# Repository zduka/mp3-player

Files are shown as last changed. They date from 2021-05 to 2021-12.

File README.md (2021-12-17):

# MP3 Player

A simple and pretty low quality mp3 player, fm radio and a walkie-talkie with some extra features. With stereo headphones (where supported) and a single even lower quality speaker in the box. MP3 files are stored on an SD card, powered by a single Li-Ion 18650 cell, with USB-C port for charging (power only). 

The player can be controlled via two push-button knobs and more advanced settings can be specified via either the player's webpage.

For a "user manual" see the documentation, this readme is for technical information only. 

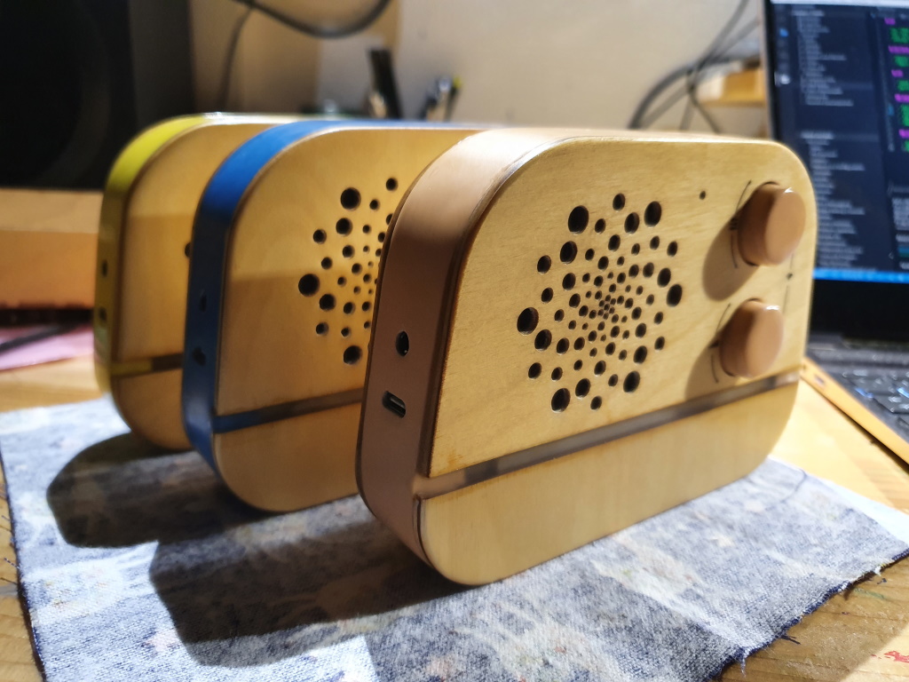
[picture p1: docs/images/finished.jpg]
Finished player


# Software

The player uses 2 MCUs - ATTiny and ESP8266. ESP acts as the main controller, while ATTiny takes care of power management and peripherals. Communication between the chips is done via I2C bus. ATTiny and the LED strip runs directly off the battery voltage, while a SMPS to 3v3 provides power for the audio output and the ESP8266. 

In sleep mode, only the ATTiny and input buttons circuitry is powered and ATTiny is in sleep mode, waking up each second for timekeeping. 

> When flashing the ESP chip, make sure power won't be terminated by ATTiny in the middle of the transaction by shorting the 3V3 jumper wire on the pcb. To perform a full reflash of both chips, start with ESP8266, when done don't reset it and flash AtTiny immediately. When AtTiny is done, it will reset (power on) the ESP as well. 

# Hardware & Assembly Guide

## Assembly Guide

> This is also heavily dependent on how tight you are with the parts and how great your soldering skills are. I was tight with parts and my soldering skills are very limited:)

### Enclosure

Glue together the upper part and the bottom corners. Make sure to insert the screw nuts in the appropriate places and glue them. Glue the bottom, left and right plates. Sand and paint the finished middle frame. 

Glue the bottom part of the front plate. Then glue in the translucent plastic strip with epoxy and the top front plate.

### USB-C Li-Ion charger

Desolder both LEDs and then put a 10k resistor (1206 is fine) instead of the charging LED (red, closer to the USB connector). Connect the charging pin to the connector closer to the connector. Desolder R3 and replace it with 2k7 resistor (through hole) directly from GND to terminal 2 of TP4056 to lower the charging current. Desolder the LEDs and replace the one closer to the USB-C connector with a 10k resistor (this will be a pull-up for the charging sense). 

Attach wires (+5V USB, +, -, charging and long connectors to the battery). When fitted in the enclosure, solder the ends to the battery holder. The battery holder is reversed so that it does not have to be glued and the wires won't obstruct the translucent LED strip below. 

### LED Strip

The LED strip consists of 8 neopixel-style LEDs soldered together. Then glue the strip in place. Make sure the glue does not obstruct the screw mountholes. 

### Main PCB

Take the 3v3 SMPS a saw off the mounthole bit and lower part of connector holes to make it castellated. Then solder the regulator, all the ICs (w/o radio and ESP8266), the MOSFETs (2x), diode and inductors. Solder the 3v3 enable header and debug header. Power on via the power connector, check first that ATTiny has power and that power levels are good and power consuption is small. Then short the 3v3 header to enable 3v3 via SMPS and check the voltage and current draw. 

Solder the capacitor for neopixels strip isolation, attach neopixels, and flash ATTiny with the neopixel test (`-DTEST_NEOPIXEL`). The pixels should flash.

Solder the remaining audio path (resistors and caps) and the radio module. Then solder the 3v3 isolation capacitors. Power on and flash ATTiny with `-DTEST_RADIO`. Attach a speaker or headphones and run. Radio should start playing (you might need to change the station frequency if you want to hear stuff). 

Solder everything else on the main board, but not the control knobs. Flash ATTiny and ESP8266 with the normal code, add empty SD card and power on. A welcome MP3 should play. 

Put the knobs in (don't solder yet), and put the whole PCB in the enclosure, attach with screws. Use hard paper strips to center the knobs in the front panel holes properly and when secured, solder the knobs. Check that everything works mechanically.

Solder the microphone board. First the IC, then all SMT parts and finally the microphone. Solder long headers, put these through the holes in pain pcb  board and when the distance is proper, solder them to the main PCB Board as well. 

Solder the antenna wire. 

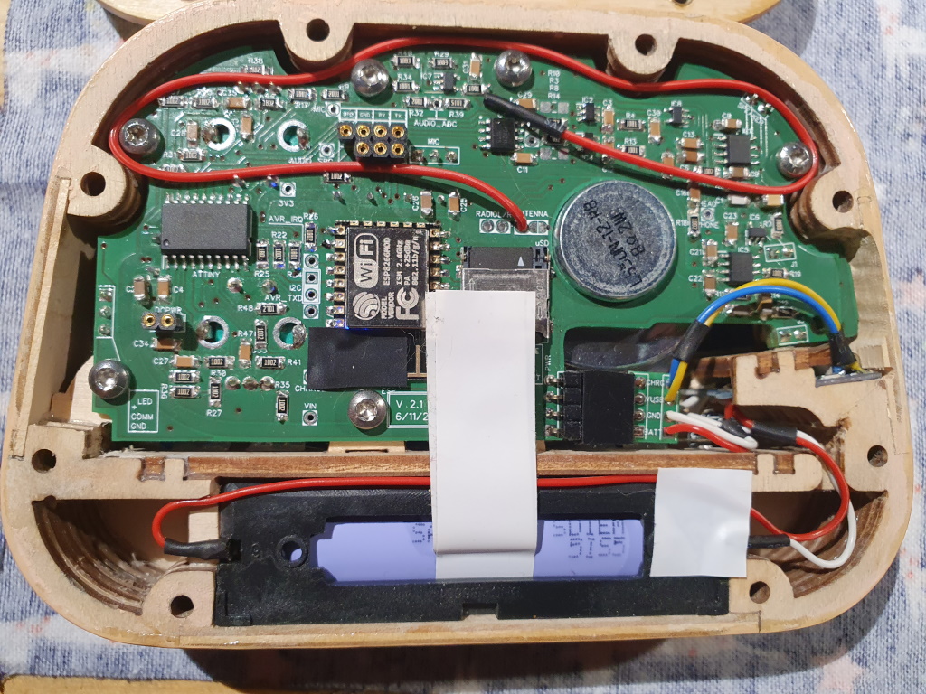
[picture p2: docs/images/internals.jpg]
Internals


### Final Assembly

Attach the speaker and slide the PCB with knobs on in the enclosure, attching the neopixels while doing so. Fix with all screws. Secure the power connector. Cover the blue ESP8266 diode. Attach the backplate.

## Main PCB Description

## ESP8266 Core

### Exceptions Decoder

- tools line in `~/snap/arduino/current/Arduino/tools`

https://github.com/me-no-dev/EspExceptionDecoder

Use old bootstrap because it is smaller

https://getbootstrap.com/docs/3.4/customize/

Bootstrap code must be updated to look for fonts in "." and then change the filenames so that they are short enouygh for littlefs (glyphicons.woff2)

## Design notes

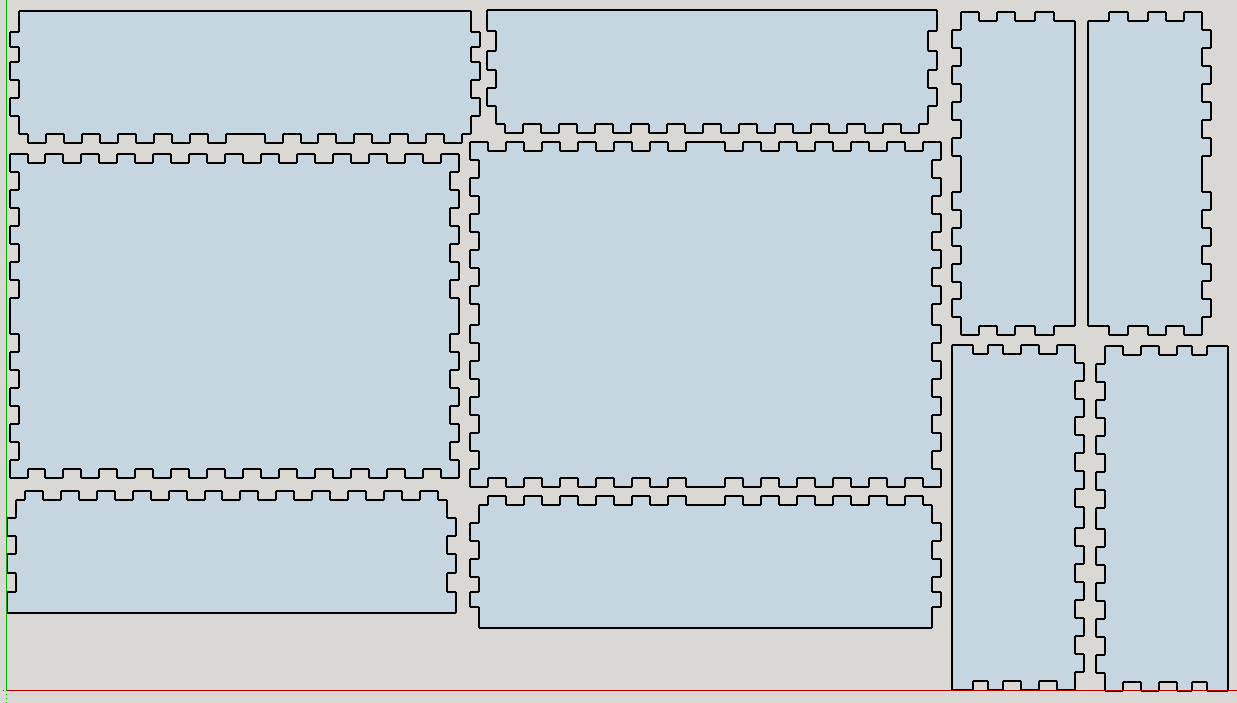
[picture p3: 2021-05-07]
hardware/box-preview.png

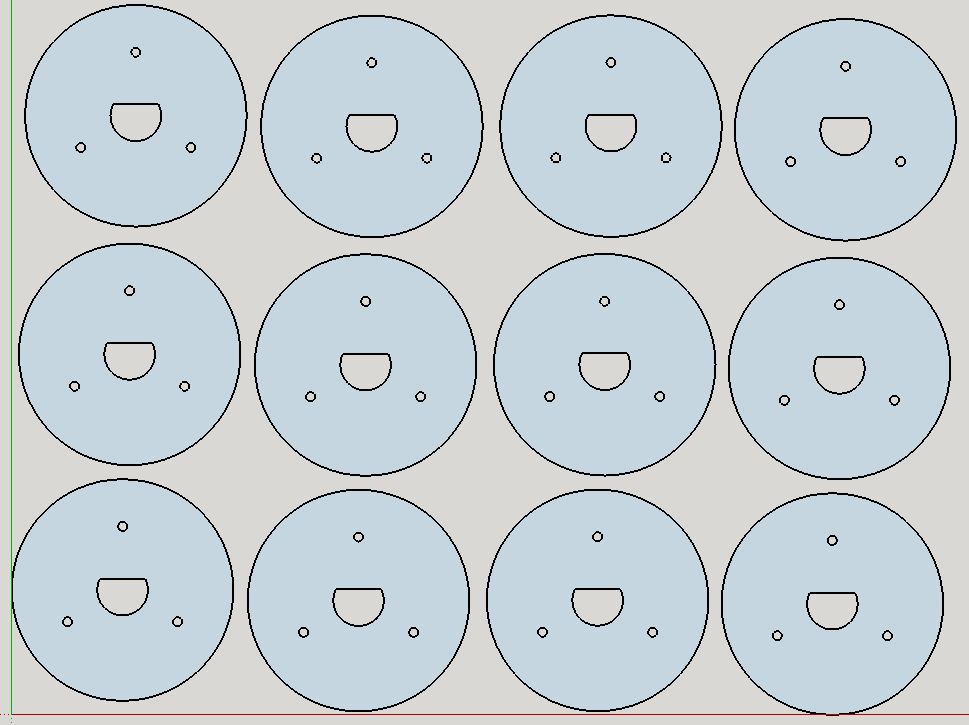
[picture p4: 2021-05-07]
hardware/plexiglass-2mm-preview.png

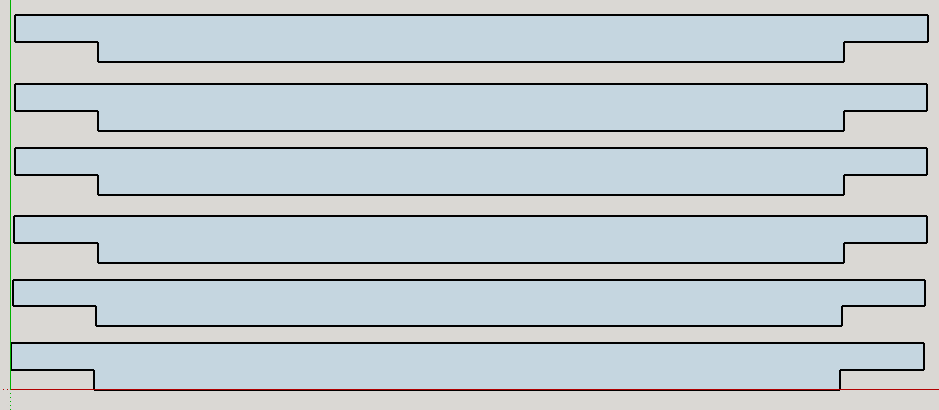
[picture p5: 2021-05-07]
hardware/plexiglass-4mm-preview.png

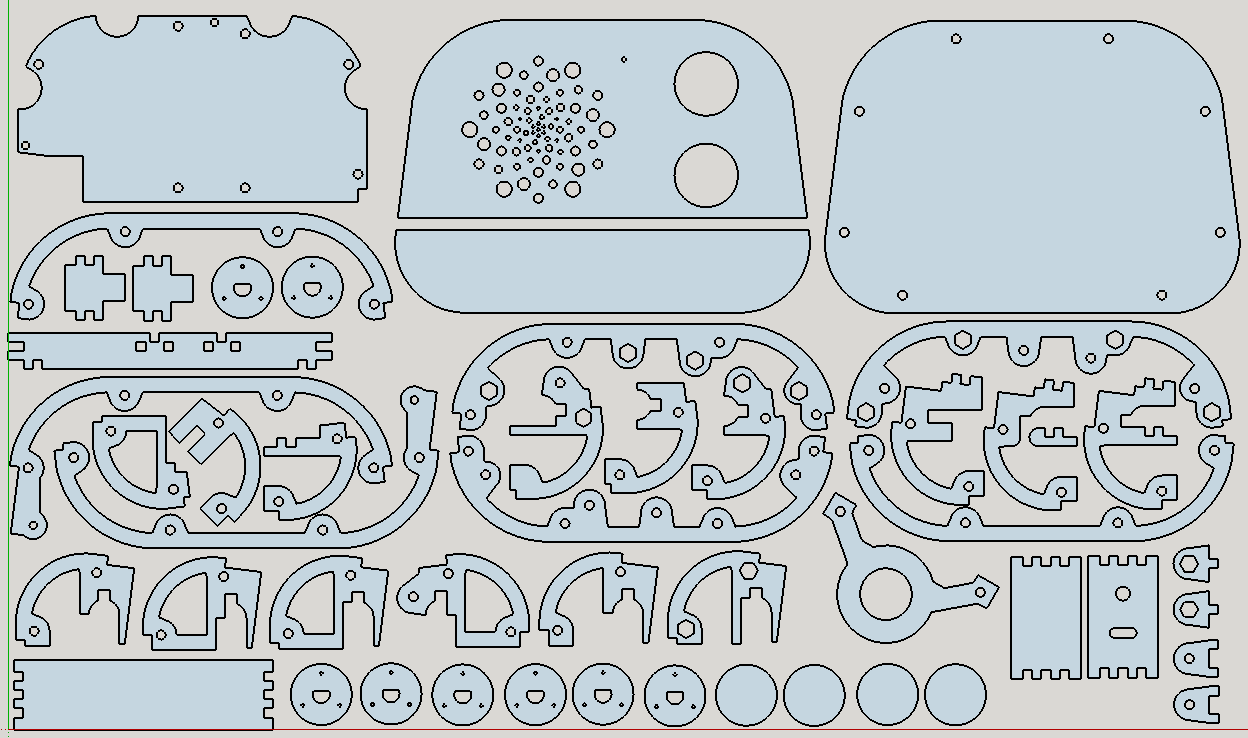
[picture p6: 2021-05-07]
hardware/player-preview.png

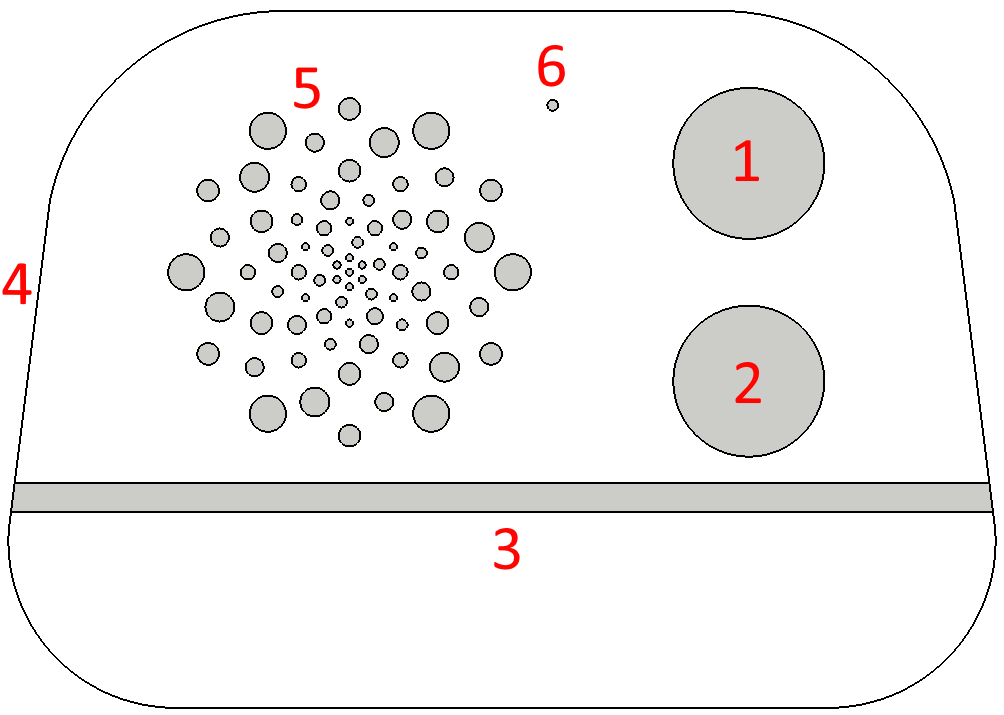
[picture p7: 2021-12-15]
docs/player.png

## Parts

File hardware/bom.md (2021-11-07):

# ICs & Semiconductors

ATTiny3216              1   13
ESP12-F                 1   2
BAT60J                  2   6       ???
TPA311                  2   7
TS5A63157               2   10
MCP6001/MCP6401         3   6/0     15/15
74LVC1G04W5-7           1   10 
DMP1045U                2   15
PT8211                  1   2/3?

# Modules & Extras

Rotary Encoder          2   5       2?      https://cz.mouser.com/ProductDetail/652-PEC12R-4220F-S24       
Microphone              1   2
Radio(RDA5807)          1   2/3?
uSD Holder              1   2
Adafruit 3V3 Buck-Boost 1   2       3    
Inductor 470uH          2   4
Speaker                 1   2               https://www.gme.cz/reproduktor-ls50n-12-r8-50mm-8ohm-2w
Headphones Conn         1   2       1       https://cz.mouser.com/ProductDetail/490-SJ-43514-SMT-TR
USB-C Li-Ion Charger    1   2
18650 Battery Holder    1   2
18650 Li-Ion Battery    1   

# Capacitors

5p                      2           10
15p                     1           10
10n                     2   /8      10
100n                    18  /66     20
0.47u                   2           10
1u                      2   /18+9   -
2u2                     2   /1      10
4u7                     1           10
10u                     3   /9      10
220u                    2   /1      4

1000u                   3

# Resistors

180R                    2   /18     -
1k                      5   /35     -
1k8                     2   /15     -
2k                      2           20
2k7                     1           10
5k1                     1           10
5k6                     1           10
10k                     24  /52     100
51k                     2           10
75k                     1           10
100k                    5   /54     -

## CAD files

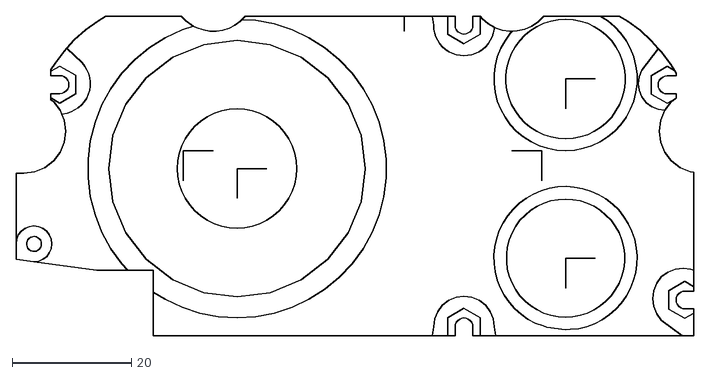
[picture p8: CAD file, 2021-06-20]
hardware/board-large.dxf
113.5 x 53.5

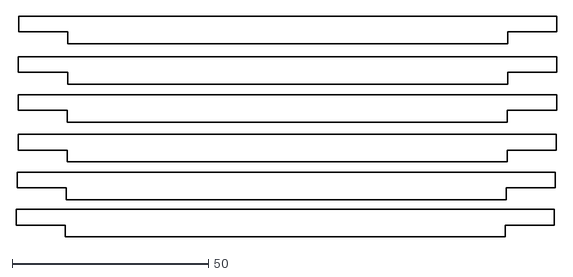
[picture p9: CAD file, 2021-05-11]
hardware/plexiglass-4mm.dxf
137.6 x 56.2

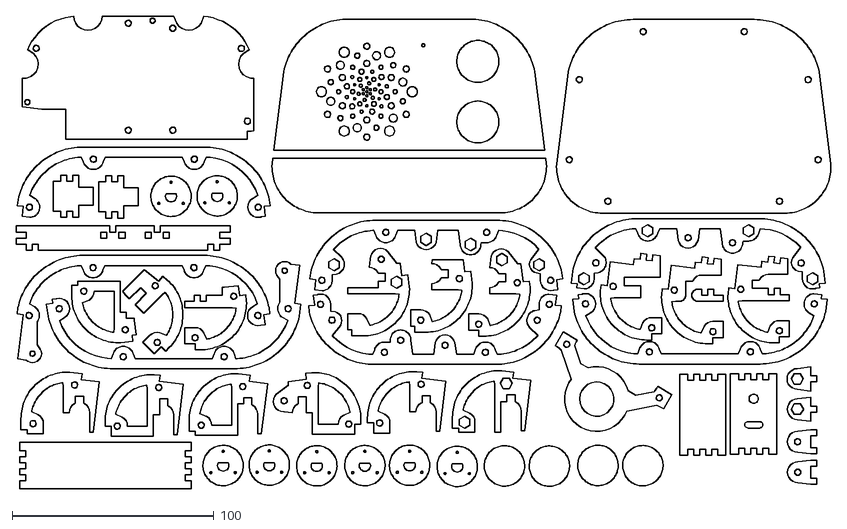
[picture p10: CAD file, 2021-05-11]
hardware/player.dxf
403.7 x 234.2

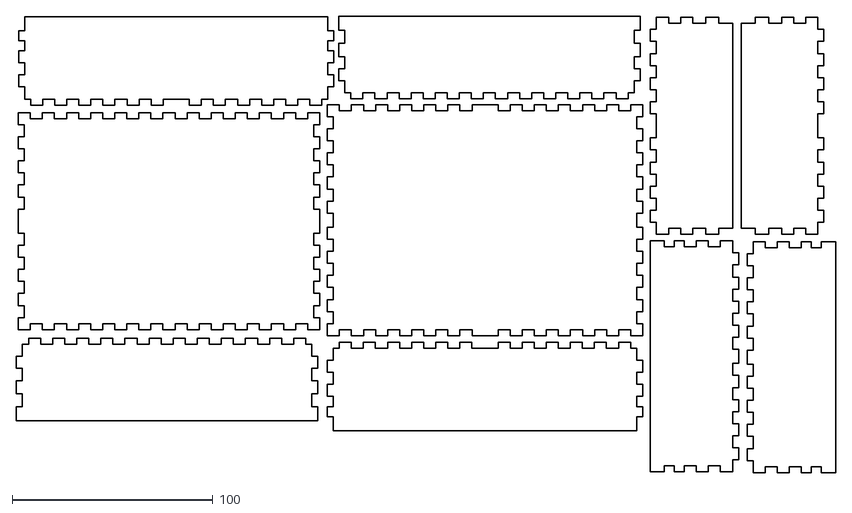
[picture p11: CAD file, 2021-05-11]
hardware/box.dxf
407.7 x 227.1

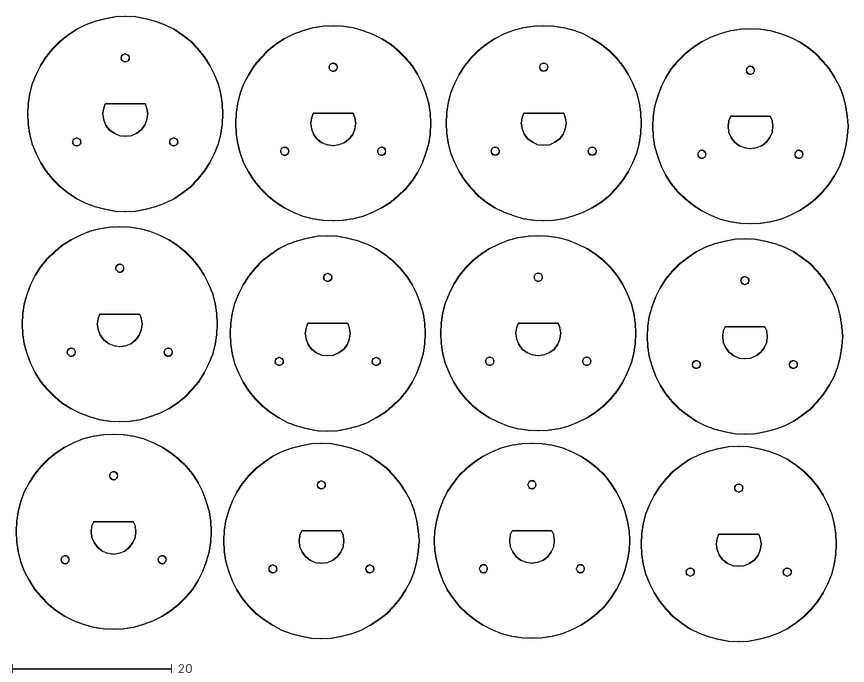
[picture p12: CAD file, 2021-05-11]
hardware/plexiglass-2mm.dxf
104.0 x 78.2

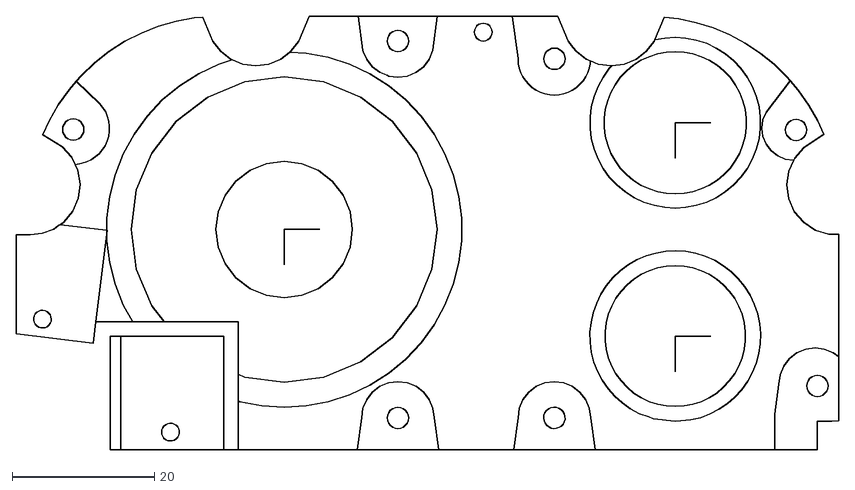
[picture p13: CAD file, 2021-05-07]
hardware/board.dxf
115.7 x 61.0

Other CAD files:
hardware/board.skp
hardware/box.skp
hardware/player.skp
hardware/plexiglass-2mm.skp
hardware/plexiglass-4mm.skp

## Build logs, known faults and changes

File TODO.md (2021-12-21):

# HW

- buy 470nF 1206 caps
- buy flux
- enlarge bypass capacitor pads

# SW

- radio stations enabled/disabled?
- check the default amplification on real settings
- getting ESP to wt mode causes problems sometimes (observed only on yellow so far)

## Disco Mode

- get WAV files for the background music
- selectable and replayable recording

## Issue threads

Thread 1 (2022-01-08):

A demo would be useful

binarweb, 2022-01-08:
Like the title states, a demo of the device actually working would increase the user count.

schmurtzm, 2022-01-13:
May interest you if you missed it :
https://zduka.github.io/mp3-player/

binarweb, 2022-01-13:
I meant a video demonstration showing and describing all the features it has.

zduka, 2022-01-22:
:) Sorry, I already gave all the units I made to the kids. If I find some time for this, or if I'd do another batch, I'll do that!

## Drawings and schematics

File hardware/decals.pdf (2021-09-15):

# Ada

# Frantisek

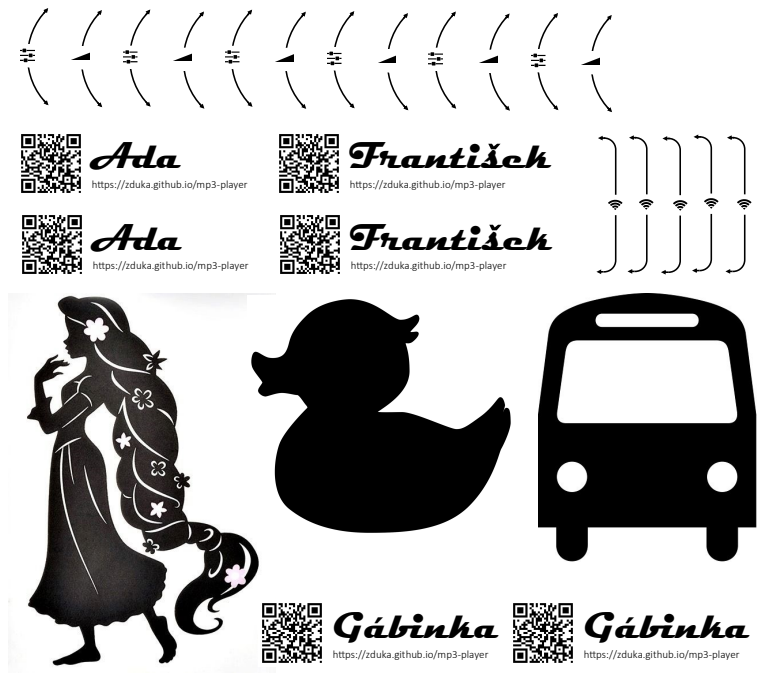
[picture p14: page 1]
Gábinka

https://zduka.github.io/mp3-player
Ada

Frantisek

## TOP LEFT

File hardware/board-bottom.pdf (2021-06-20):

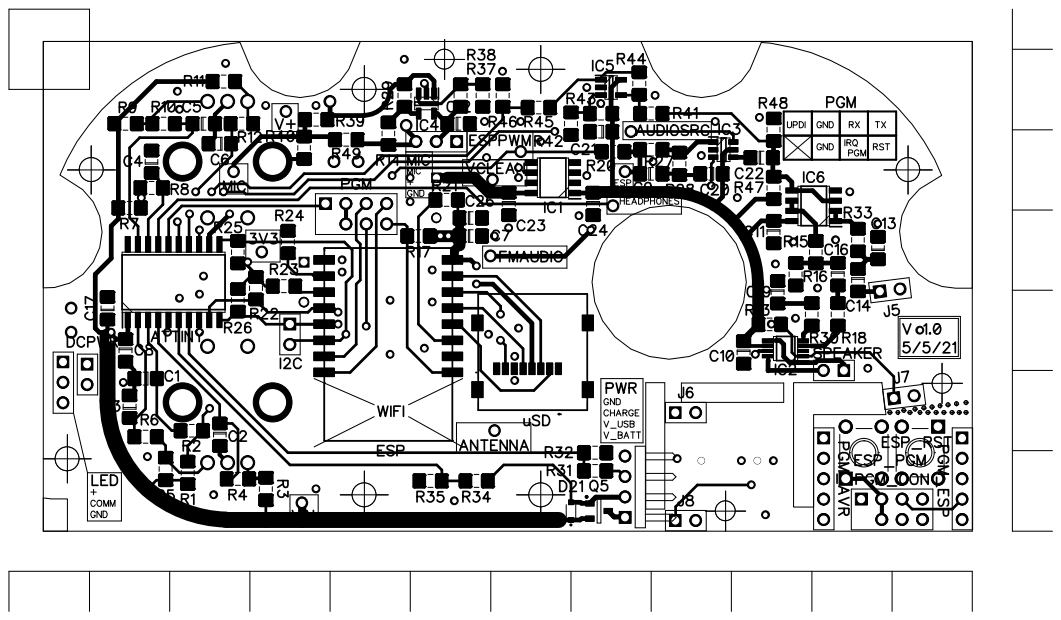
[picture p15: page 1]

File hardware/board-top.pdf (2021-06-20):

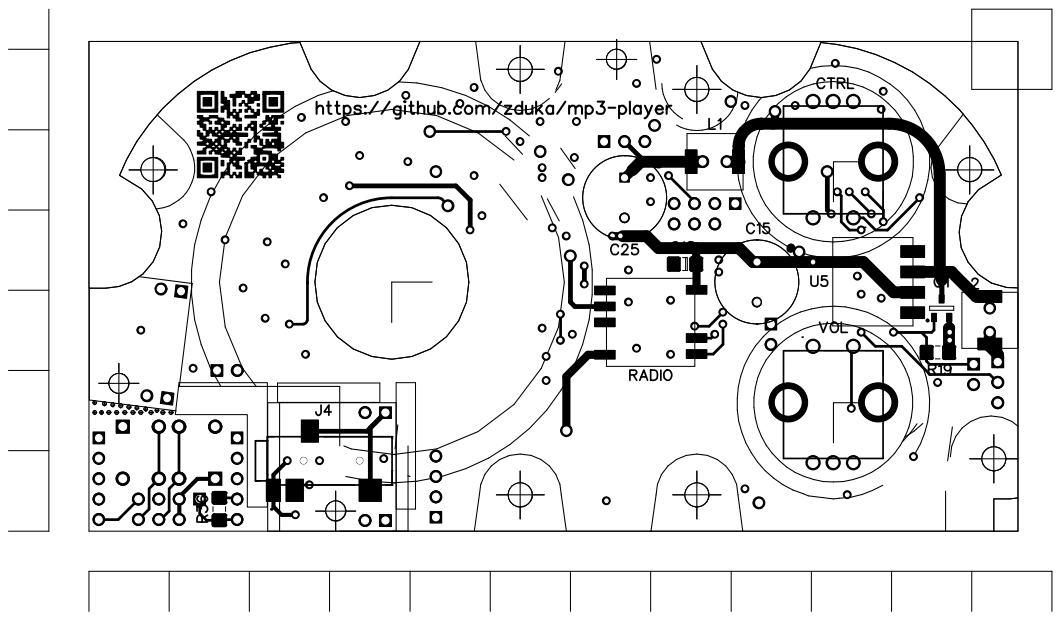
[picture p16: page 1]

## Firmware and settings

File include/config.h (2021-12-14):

#pragma once

/** Default network name and password when all else fails. 
 */
#define DEFAULT_AP_SSID "mp3-player"
#define DEFAULT_AP_PASSWORD "mp3-player"

/** Walkie talkie updates will be paused for this many minutes after each http status request. This is because updating walkie talkie and webserver at the same time leads to ESP errors in the server. 2 ,minutes are ok as the page will refresh itself every minute. 
 */
#define HTTP_STATUS_BUSY_TIMEOUT 2

/** Timeout of the player depending on whether the player is playing, or idle. In minutes, values from 1 to 255 are supported. The idle timeout is used when no playback, the play timeout is used while playing. 
 */
#define DEFAULT_IDLE_TIMEOUT 5
#define DEFAULT_PLAY_TIMEOUT 30

/** Default volumes the player will start with. 
 */
#define DEFAULT_VOLUME 5
#define DEFAULT_ALARM_VOLUME 5

/** Walkie-talkie settings. 
 
    MAX_WALKIE_TALKIE_MESSAGES: number of last messages the player remembers and plays back.
    MIN_WALKIE_TALKIE_RECORDING: minimal recording length that would be transmitted (in ms)
 */

#define MAX_WALKIE_TALKIE_MESSAGES 8
#define MIN_WALKIE_TALKIE_RECORDING 1000 * 1

/** UI Timeouts 
 
    All in ticks, the durations of UI actions:

    POWER_ON_PRESS_TICKS: How long a button has to be pressed to wake up from sleep. 
    BUTTON_LONG_PRESS_TICKS: How long a button has to be pressed to become a long press.
    BUTTON_LONG_PRESS_THRESHOLD: How long a button has to be pressed to display the long press progress bar. 
 */
#define POWER_ON_PRESS_TICKS 128
#define BUTTON_LONG_PRESS_TICKS 96
#define BUTTON_LONG_PRESS_THRESHOLD 84

/** Colors
 
    DEFAULT_COLOR: Default color to be used for the UI in the strip. 
    MODE_*: Colors for respective modes.
    BINARY_CLOCK_*: Colors for binary clock parts. 
 */
#define DEFAULT_COLOR Color::White()
#define MODE_COLOR_MP3 Color::Blue()
#define MODE_COLOR_RADIO Color::Green()
#define MODE_COLOR_DISCO Color::Purple()
#define MODE_COLOR_WALKIE_TALKIE Color::Cyan()
#define MODE_COLOR_LIGHTS Color::Yellow()
#define BINARY_CLOCK_HOURS Color::Blue()
#define BINARY_CLOCK_MINUTES Color::Green()
#define BINARY_CLOCK_BATTERY Color::Red()
#define BINARY_CLOCK_CHARGING Color::Cyan()

/** DO NOT CHANGE THE FOLLOWING SETTINGS UNLESS YOU REALLY KNOW WHAT YOU ARE DOING.
 */

/** I2C address of the AVR for communication.
 */
#define AVR_I2C_ADDRESS 67

/** Timeouts
    
    IRQ_RESPONSE_TIMEOUT: If AVR does not hear from ESP after this many ticks (1/64th second) it will restart ESP. 
    ESP_BUSY_TIMEOUT: When it busy mode for more than given number of ticks, the AVR will reset ESP. 
    SYNC_CONNECTION_TIMEOUT: How long (in seconds) ESP will wait for network connection in the sync mode. 
    SPECIAL_LIGHTS_TIMEOUT: in ticks, how long a special lights command result will be dispalyed on the strip. 
 */
#define IRQ_RESPONSE_TIMEOUT 64
#define ESP_BUSY_TIMEOUT 64 * 60 * 1
#define SYNC_CONNECTION_TIMEOUT (120 * 1000)
#define SPECIAL_LIGHTS_TIMEOUT 128

/** Radio frequency min and max values (in Mhz x 10). This must be within the chip's usable range and currently stands at 76.0 - 108.0 Mhz
 */
#define RADIO_FREQUENCY_MIN 760
#define RADIO_FREQUENCY_MAX 1080
/** Max volume of the system + 1. Comes from the radio, as on ESP we can do pretty much any granularity. 
 */
#define MAX_VOLUME 16

/** Voltage thresholds. 

    USB_VOLTAGE_THRESHOLD: Voltage above this level means the player is being powered from the USB charger.
    BATTERY_LOW_VCC: When the battery level drops below this threshold, the low battery flag is raised.
    BATTERY_CRITICAL_VCC: When battery reaches this voltage, the critical alert (three red flashes) will be displayed and the player will go to sleep immediately. 
    BATTERY_DEAD_VCC: When battery reaches this level, no warnings are displayed even and the sleep is immediately resumed. 
 */
#define USB_VOLTAGE_THRESHOLD 440
#define BATTERY_LOW_VCC 350
#define BATTERY_CRITICAL_VCC 340
#define BATTERY_DEAD_VCC 320

/** The battery undervoltage (critical or dead) must be detected consecutively for the specified number of measurements for the action to be taken to prevent the player reacting to quick power fluctuations. 
 
    Upon wakeup, the AVR waits the given ammount of time for the measurements to make sure ESP is not powered up in vain. 
 */
#define UNDERVOLTAGE_TIMEOUT 20

/** Recording settings. 
 
    MAX_RECORDING_LENGTH: Max length of a recording after which it will be stopped and either sent (walkie-talkie), or played (disco).
    RECORDING_GAIN: Amplification of recorded values. Setting this too low will mean inaudible recording, setting it too high means clipping. Depends to the mic board used. 
 */
#define MAX_RECORDING_LENGTH 1000 * 30
#define RECORDING_GAIN 5

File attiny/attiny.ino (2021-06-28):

#include <avr/sleep.h>
#include <Wire.h>

#include "state.h"
#include "inputs.h"
#include "neopixel.h"

/** Chip Pinout

               -- VDD             GND --
         VOL_B -- (00) PA4   PA3 (16) -- CTRL_A
       VOL_BTN -- (01) PA5   PA2 (15) -- CTRL_BTN
         VOL_A -- (02) PA6   PA1 (14) -- HEADPHONES
      DCDC_PWR -- (03) PA7   PA0 (17) -- UPDI
     V_CHARGER -- (04) PB5   PC3 (13) -- CTRL_B
      CHARGING -- (05) PB4   PC2 (12) -- AUDIO_ADC
      NEOPIXEL -- (06) PB3   PC1 (11) -- AUDIO_SRC
       AVR_IRQ -- (07) PB2   PC0 (10) -- MIC
           SDA -- (08) PB1   PB0 (09) -- SCL
 */

#define DCDC_PWR 3
#define NEOPIXEL 6
#define CTRL_A 16
#define CTRL_B 13
#define CTRL_BTN 15
#define VOL_A 2
#define VOL_B 0
#define VOL_BTN 1
#define AVR_IRQ 7
#define AUDIO_SRC 11
#define AUDIO_ADC 12
#define HEADPHONES 14
#define MIC 10

#define AUDIO_ESP HIGH
#define AUDIO_RADIO LOW

extern "C" void RTC_PIT_vect(void) __attribute__((signal));
extern "C" void ADC0_RESRDY_vect(void) __attribute__((signal));
extern "C" void ADC1_RESRDY_vect(void) __attribute__((signal));

/** The MP3 Player Device Controller

    # RTC

    The internal RTC in the attiny is used to keep a semi-precise track of time. When the chip is on, a tick is generated every 1/32th of second so that it can be used to drive neopixels, etc. When the device sleeps, a one second tick is used to save battery and only the time is updated and alarm checked. 
 */
class AVRPlayer {
public:

    /** Setup is executed when powered on. 

        Technically, this can only happen after a reset, or after BOD when voltage gets high again due to charging, or new battery. As such, we can simply assume enough battery is present and power stuff without checking voltage. 
     */
    void setup() {
        // enable the AVR_IRQ as input
        pinMode(AVR_IRQ, INPUT);
        // disable 3v, audio and neopixel rails
        pinMode(DCDC_PWR, INPUT);
        // configure the real time clock
        RTC.CLKSEL = RTC_CLKSEL_INT32K_gc; // select internal oscillator
        RTC.PITINTCTRL |= RTC_PI_bm; // enable the interrupt
        // set audio source to esp8266
        pinMode(AUDIO_SRC, OUTPUT);
        digitalWrite(AUDIO_SRC, AUDIO_ESP);
        // enable the ADC inputs (audio, mic, voltage), disable the digital input buffers and pull-up resistors
        // NOTE this requires that the pins stay the same
        static_assert(AUDIO_ADC == 12, "Must be PC2"); // ADC1 input 8
        PORTC.PIN2CTRL &= ~PORT_ISC_gm;
        PORTC.PIN2CTRL |= PORT_ISC_INPUT_DISABLE_gc;
        PORTC.PIN2CTRL &= ~PORT_PULLUPEN_bm;
        static_assert(MIC == 10, "Must be PC0"); // ADC1 input 6
        PORTC.PIN0CTRL &= ~PORT_ISC_gm;
        PORTC.PIN0CTRL |= PORT_ISC_INPUT_DISABLE_gc;
        PORTC.PIN0CTRL &= ~PORT_PULLUPEN_bm;
        static_assert(HEADPHONES == 14, "Must be PA1"); // ADC0 input 1
        PORTA.PIN1CTRL &= ~PORT_ISC_gm;
        PORTA.PIN1CTRL |= PORT_ISC_INPUT_DISABLE_gc;
        PORTA.PIN1CTRL &= ~PORT_PULLUPEN_bm;

        // set sleep to full power down and enable sleep feature
        set_sleep_mode(SLEEP_MODE_PWR_DOWN);
        sleep_enable();         
        // setup ADC0 and ADC1 settings
        // set reference to 1.1V
        VREF.CTRLA &= ~ VREF_ADC0REFSEL_gm;
        VREF.CTRLA |= VREF_ADC0REFSEL_1V1_gc;
        VREF.CTRLC &= ~ VREF_ADC1REFSEL_gm;
        VREF.CTRLC |= VREF_ADC1REFSEL_1V1_gc;
        // clkdiv by 4, internal voltage reference
        ADC1.CTRLC = ADC_PRESC_DIV4_gc | ADC_REFSEL_INTREF_gc | ADC_SAMPCAP_bm; // 2mhz
        // delay 32us and sampctrl of 32 us for the temperature sensor, do averaging over 16 values
        ADC0.CTRLA = ADC_ENABLE_bm | ADC_RESSEL_10BIT_gc;
        ADC0.CTRLB = ADC_SAMPNUM_ACC64_gc;
        ADC0.CTRLC = ADC_PRESC_DIV16_gc | ADC_REFSEL_VDDREF_gc | ADC_SAMPCAP_bm; // 0.5mhz
        ADC0.CTRLD = ADC_INITDLY_DLY32_gc;
        ADC0.SAMPCTRL = 31;
        // start the vcc & temp & headphones sensing, enable interrupt and measure the VCC once more
        ADC0.MUXPOS = ADC_MUXPOS_INTREF_gc;
        ADC0.INTCTRL |= ADC_RESRDY_bm;
        ADC0.COMMAND = ADC_STCONV_bm;
        // enable I2C slave
        Wire.begin(AVR_I2C_ADDRESS);
        Wire.onRequest(I2CSendEventTrampoline);
        Wire.onReceive(I2CReceiveEventTrampoline);
        // attach the interrupts
        volume_.setInterrupt(VolumeChangedTrampoline);
        control_.setInterrupt(ControlChangedTrampoline);
        volumeButton_.setInterrupt(VolumeButtonChangedTrampoline);
        controlButton_.setInterrupt(ControlButtonChangedTrampoline);
        // and continue as if waking up from sleep
        wakeup();
    }
    
    void loop() {
        if (rtcTick()) {
            if (irq_.enabled && --irq_.timer == 0) {
                resetEsp();
            } else {
                // update the lights
                lightsTick();
            }
        }
        if (rtcTickSecond()) {
            if (state_.idle() && sleep_.countdown > 0) {
                if (--sleep_.countdown == 0)
                    sleep();
            }
        }
    }

private:

    static constexpr unsigned AVR_ACTIVE = 0;
    static constexpr unsigned AVR_SLEEPING = 1;
    static constexpr unsigned AVR_WAKING = 2;

    /** The sleep state and countdown. 
     */
    volatile struct {
        unsigned state : 2;
        unsigned countdown : 6;        
    } sleep_;


    void setIdle(bool value) {
        state_.setIdle(value);
        if (value) {
            sleep_.countdown = 60;
        }
    }
    
    /** Enters sleep mode. 

        
     */
    void sleep() {
        neopixels_.showBar(8,8,Neopixel::Red());
        neopixels_.sync();
        delay(300);
        neopixels_.setAll(Neopixel::Black());
        neopixels_.sync();
        // set audio src to 0 so that we don't bleed voltage
        digitalWrite(AUDIO_SRC, LOW);
        // turn of power to 3v3 and 5v
        powerOff();
        // going to sleep
        sleep_.state = AVR_SLEEPING;
        // change rtc period to 1 second
        RTC.PITCTRLA = RTC_PERIOD_CYC32768_gc + RTC_PITEN_bm; // enable PTI and set the tick to 1/32th of second
        // disable interrupts for rotary encoders (we only keep the buttons)
        // TODO
        

        // since we will keep receiving the RTC interrupts every 1 second, we'll sleep immediately afterwards unless it is a button interrupt which clears the sleep flag
        while (sleep_.state != AVR_ACTIVE)
            sleep_cpu();
        // here we wake up
        wakeup();
    }

    void wakeup() {
        RTC.PITCTRLA = RTC_PERIOD_CYC1024_gc + RTC_PITEN_bm; // enable PTI and set the tick to 1/32th of second
        // wake-up to non-idle mode
        setIdle(false);
        powerOn();
        // if current mode is radio, make sure to to enable the source
        if (state_.mode() == State::Mode::Radio)
            digitalWrite(AUDIO_SRC, AUDIO_RADIO);
        else
            digitalWrite(AUDIO_SRC, AUDIO_ESP);
        delay(100);
        neopixels_.showBar(8,8,Neopixel::Green());
        neopixels_.sync();
        delay(300);
        neopixels_.setAll(Neopixel::Black());
        neopixels_.sync();
    }

    void setMode(State::Mode mode) {
        state_.setMode(mode);
        switch (mode) {
            case State::Mode::MP3:
                enableAudioADC();
                digitalWrite(AUDIO_SRC, AUDIO_ESP);
                controlColor_ = state_.mp3PlaylistSelection() ? MP3_PLAYLIST_COLOR : MP3_TRACK_COLOR;
                break;
            case State::Mode::Radio:
                enableAudioADC();
                digitalWrite(AUDIO_SRC, AUDIO_RADIO);
                controlColor_ = state_.radioManualTuning() ? RADIO_FREQUENCY_COLOR : RADIO_STATION_COLOR;
                break;
        }
    }

    
    void setVolume(uint8_t value) {
        if (value != state_.audioVolume()) 
            state_.setAudioVolume(value);
        neopixels_.showBar(state_.audioVolume(), 15, VOLUME_COLOR.withBrightness(brightness_));
        specialLights_ = SPECIAL_LIGHTS_TIMEOUT;
    }

    void setControl(uint16_t value) {
        if (value != state_.control()) 
            state_.setControl(value);
        neopixels_.showPoint(state_.control(), control_.maxValue() - 1, controlColor_.withBrightness(brightness_));
        specialLights_ = SPECIAL_LIGHTS_TIMEOUT;
    }

    /** Returns true if there was an RTC tick since the last call to the function. 

        An RTC tick occurs every 1/32th of a second. 
     */
    bool rtcTick() const {
        if (rtcTick_.tick) {
            rtcTick_.tick = 0;
            return true;
        } else {
            return false;
        }
    }

    /** Returns true if there was a second tick since the last call to the function. 
     */
    bool rtcTickSecond() const {
        if (rtcTick_.tickSecond) {
            rtcTick_.tickSecond = 0;
            return true;
        } else {
            return false;
        }
    }

    void powerOn() {
        pinMode(DCDC_PWR,OUTPUT);
        digitalWrite(DCDC_PWR, LOW);
        state_.state_ |= State::STATE_DCDC_POWER; 
        delay(50);
    }

    void powerOff() {
        pinMode(DCDC_PWR, INPUT);
        state_.state_ &= ~State::STATE_DCDC_POWER;
    }

    /** Resets the ESP8266. 
     */
    void resetEsp() {
        clearIrq();
        neopixels_.setAll(Neopixel::Red());
        neopixels_.sync();
        delay(100);
        neopixels_.setAll(Neopixel::Black());
        neopixels_.sync();
        pinMode(DCDC_PWR,INPUT);
        delay(500);
        pinMode(DCDC_PWR,OUTPUT);
        digitalWrite(DCDC_PWR, LOW);
        // TODO add wake signal
    }

    /** Sets the IRQ to ping the esp8266. 
     */
    bool setIrq() {
        if (!irq_.enabled) {
            irq_.enabled = true;
            irq_.timer = IRQ_MAX_DELAY;
            pinMode(AVR_IRQ,OUTPUT);
            digitalWrite(AVR_IRQ, LOW);
            return true;
        } else {
            return false;
        }
    }

    void clearIrq() {
        if (irq_.enabled) {
            irq_.enabled = false;
            state_.clearEvents();
            pinMode(AVR_IRQ, INPUT);
        }
    }

    void rtcDisable() {
        RTC.PITCTRLA &= ~ RTC_PITEN_bm;
    }

    void doRtcTick() {
        if (sleep_.state != AVR_SLEEPING) {
            rtcTick_.tick = 1;
            if (++rtcTick_.counter == 0) {
                rtcTick_.tickSecond = 1;
                clock_.secondTick();
            }
            // if the buttons are pressed, decrement their down ticks so that long presses can be determined, if the long press is the wakeup press clear the state for given button so that it won't register
            if (volBtnDownTicks_ > 0)
                if (--volBtnDownTicks_ == 0 && sleep_.state == AVR_WAKING) {
                    state_.state_ &= ~State::STATE_VOL_BTN;
                    sleep_.state = AVR_ACTIVE;
                }
            if (ctrlBtnDownTicks_ > 0)
                if (--ctrlBtnDownTicks_ == 0 && sleep_.state == AVR_WAKING) {
                    state_.state_ &= ~State::STATE_CTRL_BTN;
                    sleep_.state = AVR_ACTIVE;
                }
        } else {
            clock_.secondTick();
        }
    }


    /** \name Lights

     */
    //@{
    NeopixelStrip<NEOPIXEL, 8> neopixels_;
    uint8_t specialLights_ = 0;
    Neopixel accentColor_ = Neopixel::White();
    Neopixel controlColor_;
    /** Maximum brightness of the strip. 
     */
    uint8_t brightness_ = 32;

    void lightsTick() {
        if (state_.volumeButtonDown() || state_.controlButtonDown()) {
            uint8_t v = BUTTON_LONG_PRESS_TICKS - max(volBtnDownTicks_, ctrlBtnDownTicks_);
            if (v == BUTTON_LONG_PRESS_TICKS)
                neopixels_.setAll(BUTTONS_LONG_PRESS_COLOR.withBrightness(brightness_));
            else 
                neopixels_.showBar(v, BUTTON_LONG_PRESS_TICKS, BUTTONS_COLOR.withBrightness(brightness_));
        } else {
            if (specialLights_ == 0) {
                if (state_.audioLights())
                    updateAudioBar();
            } else if (--specialLights_ == 0) {
                neopixels_.setAll(Neopixel::Black());
            }
        }
        neopixels_.tick(max(brightness_ / 16, 1));
    }
    //@}

    /** \name Controls
     */
    //@{

    /** The control (top) and volume (down) knobs (rotary encoders and buttons). 
     */
    RotaryEncoder control_{CTRL_A, CTRL_B, 256};
    RotaryEncoder volume_{VOL_A, VOL_B, 16};
    Button controlButton_{CTRL_BTN};
    Button volumeButton_{VOL_BTN};
    uint8_t volBtnDownTicks_ = 0;
    uint8_t ctrlBtnDownTicks_ = 0;

    void volumeChanged() {
        volume_.poll();
        setVolume(volume_.value());
        setIrq();
    }

    void controlChanged() {
        control_.poll();
        setControl(control_.value());
        setIrq();
    }

    void volumeButtonChanged() {
        volumeButton_.poll();
        if (volumeButton_.pressed()) {
            if (sleep_.state == AVR_SLEEPING) {
                // switch RTC to every 1/32th second
                RTC.PITCTRLA = RTC_PERIOD_CYC1024_gc + RTC_PITEN_bm; 
                sleep_.state = AVR_WAKING;
            } 
            volBtnDownTicks_ = BUTTON_LONG_PRESS_TICKS;
            state_.state_ |= State::STATE_VOL_BTN;
        // if this was waking-up press, it has been cleared so that it won't register
        } else if (state_.volumeButtonDown()){
            state_.state_ &= ~State::STATE_VOL_BTN;
            // go back to sleep if the threshold has not been reached
            if (sleep_.state == AVR_WAKING) {
                sleep_.state = AVR_SLEEPING;
                // switch RTC to once a second
                RTC.PITCTRLA = RTC_PERIOD_CYC32768_gc + RTC_PITEN_bm;
                return;
            }
            state_.events_ |= (volBtnDownTicks_ == 0) ? State::EVENT_VOL_LONG_PRESS : State::EVENT_VOL_PRESS;
            neopixels_.setAll(Neopixel::Black());
            setIrq();
        }
    }

    void controlButtonChanged() {
        controlButton_.poll();
        if (controlButton_.pressed()) {
            if (sleep_.state == AVR_SLEEPING) {
                // switch RTC to every 1/32th second
                RTC.PITCTRLA = RTC_PERIOD_CYC1024_gc + RTC_PITEN_bm; 
                sleep_.state = AVR_WAKING;
            } 
            ctrlBtnDownTicks_ = BUTTON_LONG_PRESS_TICKS;
            state_.state_ |= State::STATE_CTRL_BTN;
        // if this was waking-up press, it has been cleared so that it won't register
        } else if (state_.controlButtonDown()){
            state_.state_ &= ~State::STATE_CTRL_BTN;
            // go back to sleep if the threshold has not been reached
            if (sleep_.state == AVR_WAKING) {
                sleep_.state = AVR_SLEEPING;
                // switch RTC to once a second
                RTC.PITCTRLA = RTC_PERIOD_CYC32768_gc + RTC_PITEN_bm;
                return;
            }
            state_.events_ |= (ctrlBtnDownTicks_ == 0) ? State::EVENT_CTRL_LONG_PRESS : State::EVENT_CTRL_PRESS;
            neopixels_.setAll(Neopixel::Black());
            setIrq();
        }
    }
    //@}

    /** \name I2C 
     */
    //@{

    uint8_t cmdBuffer_[32];
    
    void i2cSendEvent() {
        // casting away the volatile-ness is ok here 
        Wire.write(pointer_cast<uint8_t*>(const_cast<State*>(& state_)), sizeof (State));
        // clear the irq and events once we have given them to master
        clearIrq();
        state_.events_ = 0;
    }

    void i2cReceiveEvent(int numBytes) {
        Wire.readBytes(pointer_cast<uint8_t*>(& cmdBuffer_), numBytes);
        switch (cmdBuffer_[0]) {
            case Command::SetMode::Id: {
                Command::SetMode * cmd = pointer_cast<Command::SetMode*>(& cmdBuffer_[1]);
                setMode(cmd->mode);
                break;
            }
            case Command::SetIdle::Id: {
                Command::SetIdle * cmd = pointer_cast<Command::SetIdle*>(& cmdBuffer_[1]);
                setIdle(cmd->idle);
                break;
            }
            case Command::SetVolume::Id: {
                Command::SetVolume * cmd = pointer_cast<Command::SetVolume*>(& cmdBuffer_[1]);
                volume_.setValue(cmd->value);
                setVolume(cmd->value);
                break;
            }
            case Command::SetControl::Id: {
                Command::SetControl * cmd = pointer_cast<Command::SetControl*>(& cmdBuffer_[1]);
                control_.setMaxValue(cmd->maxValue);
                control_.setValue(cmd->value);
                setControl(cmd->value);
                break;
            }
            case Command::SetRadioState::Id: {
                Command::SetRadioState * cmd = pointer_cast<Command::SetRadioState*>(& cmdBuffer_[1]);
                state_.setRadioStation(cmd->station);
                state_.setRadioFrequency(cmd->frequency);
                state_.setRadioManualTuning(cmd->manualTuning);
                controlColor_ = state_.radioManualTuning() ? RADIO_FREQUENCY_COLOR : RADIO_STATION_COLOR;
                break;
            }
                
            case Command::SetMP3State::Id: {
                Command::SetMP3State * cmd = pointer_cast<Command::SetMP3State*>(& cmdBuffer_[1]);
                state_.setMp3PlaylistId(cmd->playlist);
                state_.setMp3TrackId(cmd->track);
                state_.setMp3PlaylistSelection(cmd->playlistSelection);
                controlColor_ = state_.mp3PlaylistSelection() ? MP3_PLAYLIST_COLOR : MP3_TRACK_COLOR;
                break;
            }
                
            case Command::SetAudioLights::Id: {
                Command::SetAudioLights * cmd = pointer_cast<Command::SetAudioLights*>(& cmdBuffer_[1]);
                state_.setAudioLights(cmd->on);
                neopixels_.setAll(Neopixel::Black());
                break;
            }
            case Command::SetBrightness::Id: {
                Command::SetBrightness * cmd = pointer_cast<Command::SetBrightness*>(& cmdBuffer_[1]);
                brightness_ = cmd->brightness;
                break;
            }
            case Command::SetAccentColor::Id: {
                Command::SetAccentColor * cmd = pointer_cast<Command::SetAccentColor*>(& cmdBuffer_[1]);
                accentColor_.r = cmd->red;
                accentColor_.g = cmd->green;
                accentColor_.b = cmd->blue;
                break;
            }
            case Command::SpecialLights::Id: {
                Command::SpecialLights * cmd = pointer_cast<Command::SpecialLights*>(& cmdBuffer_[1]);
                Neopixel color{cmd->red, cmd->green, cmd->blue};
                switch (cmd->mode) {
                    case Command::SpecialLights::POINT:
                        neopixels_.showPoint(cmd->value, cmd->maxValue, color);
                        break;
                    case Command::SpecialLights::BAR:
                        neopixels_.showBar(cmd->value, cmd->maxValue, color);
                        break;
                    case Command::SpecialLights::CENTERED_BAR:
                        neopixels_.showCenteredBar(cmd->value, cmd->maxValue, color);
                        break;
                }
                specialLights_ = cmd->duration;
                break;
            }
            case Command::Lights::Id: {
                Command::Lights * cmd = pointer_cast<Command::Lights*>(& cmdBuffer_[1]);
                for (uint8_t i = 0; i < 8; ++i) {
                    Neopixel & p = neopixels_[i];
                    p.r = cmd->colors[i * 3];
                    p.g = cmd->colors[i * 3 + 1];
                    p.b = cmd->colors[i * 3 + 2];
                }
                specialLights_ = cmd->duration;
                break;
            }
            default:
                break;
        }
    }
    
    //@}

    /** Device state. 
     */
    volatile State state_;
    volatile Clock clock_;
    
    
    //@}








    /** RTC ticks counter, there are 32 ticks in one second. 
     */
    mutable volatile struct {
        unsigned tick : 1;
        unsigned tickSecond : 1;
        unsigned counter : 5; // 0..31
    } rtcTick_;

    mutable volatile struct {
        unsigned enabled : 1;
        unsigned timer : 7;
    } irq_;

    /** \name ADC0 - Voltage, temperature and headphones
     */
    //@{

    void setVoltageFromADC(uint16_t adc) {
        // kind of complicated so that we stay in the 16bit unsigned, which 110 * 1024 won't give us
        adc = 110 * 512 / adc;
        adc = adc * 2;
        // convert adc to voltage times 100, i.e. in range 0..110, but anything below 0.55 volts gets compressed to 0
        //adc = (adc > 512) ? ((adc - 512) * 110 / 1023) + 55 : 0;
        // update to real voltage using the voltage divider
        //adc = adc * (VCC_DIVIDER_RES1 + VCC_DIVIDER_RES2) / VCC_DIVIDER_RES2;
        state_.setVoltage(adc);
    }

    void setTemperatureFromADC(uint16_t temp) {
        int8_t sigrow_offset = SIGROW.TEMPSENSE1; // Read signed value from signature row
        uint8_t sigrow_gain = SIGROW.TEMPSENSE0;
        temp -= sigrow_offset >> 2;
        temp *= (sigrow_gain >> 2); // so that we won't overflow 16bit value
        state_.setTemperature(temp);
    }
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
void loop() {
    player.loop();
}

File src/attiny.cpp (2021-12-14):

#if (defined ARCH_ATTINY)

#if (F_CPU!=8000000UL)
//#error "Only 8Mhz clock is supported"
#endif

#include <Arduino.h>

#include <avr/sleep.h>
#include <util/delay.h>
#include <util/atomic.h>

#if (defined TEST_RADIO)
#include <radio.h>
#include <RDA5807M.h>
#endif

#include "config.h"
#include "state.h"
#include "messages.h"
#include "attiny/inputs.h"
#include "attiny/neopixel.h"

/** Chip Pinout

               -- VDD             GND --
         VOL_B -- (00) PA4   PA3 (16) -- CTRL_A
       VOL_BTN -- (01) PA5   PA2 (15) -- CTRL_BTN
         VOL_A -- (02) PA6   PA1 (14) -- HEADPHONES
      DCDC_PWR -- (03) PA7   PA0 (17) -- UPDI
      NEOPIXEL -- (04) PB5   PC3 (13) -- CTRL_B
      CHARGING -- (05) PB4   PC2 (12) -- AUDIO_ADC
       AVR_IRQ -- (06) PB3   PC1 (11) -- AUDIO_SRC
               -- (07) PB2   PC0 (10) -- MIC
           SDA -- (08) PB1   PB0 (09) -- SCL
 */

#define DCDC_PWR 3
#define NEOPIXEL 4
#define CTRL_A 16
#define CTRL_B 13
#define CTRL_BTN 15
#define VOL_A 2
#define VOL_B 0
#define VOL_BTN 1
#define AVR_IRQ 6
#define AUDIO_SRC 11
#define AUDIO_ADC 12
#define HEADPHONES 14
#define MIC 10
#define DEBUG_PIN 7
#define CHARGING 5


#define AUDIO_SRC_ESP HIGH
#define AUDIO_SRC_RADIO LOW

#define DCDC_PWR_ON LOW
#define DCDC_PWR_OFF HIGH


extern "C" void RTC_PIT_vect(void) __attribute__((signal));
extern "C" void TWI0_TWIS_vect(void) __attribute__((signal));
extern "C" void ADC1_RESRDY_vect(void) __attribute__((signal));

/** We need the actual transmissible state to be in a own structure, guaranteeing that state and extended state are right next to each other in memory.
 */
class AVRState {
public:
    volatile State state;
    ExtendedState ex;
} __attribute__((packed));

static_assert(sizeof(AVRState) == sizeof(State) + sizeof(ExtendedState));

#if (defined TEST_NEOPIXEL)

/** Displays various colors on the neopixel strip after turning on 3v3. 
 */
void setup() {
    NeopixelStrip<NEOPIXEL, 8> neopixels;
    pinMode(DCDC_PWR, OUTPUT);
    digitalWrite(DCDC_PWR, LOW);
    delay(50);
    neopixels[0] = Color::Red();
    neopixels[1] = Color::Green();
    neopixels[2] = Color::Blue();
    neopixels[3] = Color::Purple();
    neopixels[4] = Color::Yellow();
    neopixels[5] = Color::Cyan();
    neopixels[6] = Color::White();
    neopixels[7] = Color::Red();
    neopixels.update();
}
void loop() { 
}

#elif (defined TEST_RADIO)

/** Starts the radio at lowest volume and preset station while displaying a moving light on the neopixels. 
 */

RDA5807M radio;
NeopixelStrip<NEOPIXEL, 8> neopixels;
uint8_t x = 0;

void setup() {
    pinMode(DCDC_PWR, OUTPUT);
    digitalWrite(DCDC_PWR, DCDC_PWR_ON);
    pinMode(AUDIO_SRC, OUTPUT);
    digitalWrite(AUDIO_SRC, AUDIO_SRC_RADIO);
    //pinMode(HEADPHONES, OUTPUT);
    //digitalWrite(HEADPHONES, LOW);
    delay(50);
    Wire.begin();
    radio.init();
    delay(50);
    radio.setMono(true);
    delay(50);
    radio.setVolume(1);
    delay(50);
    radio.setBandFrequency(RADIO_BAND_FM, 9370);
}
void loop() { 
    neopixels.showPoint(x, 255, Color::White().withBrightness(32));
    neopixels.update();
    delay(30);
    ++x;
    //if (x % 16 == 0)
    //    radio.setVolume(x >> 4);
}

#else 

/** The actual player. 
  */
class Player {
public:
    static void initialize() {
#ifdef DEBUG_LOG
        Serial.begin(115200);
#endif
        pinMode(DEBUG_PIN, OUTPUT);
        digitalWrite(DEBUG_PIN, LOW);
        delay(10);
        USART0.CTRLB &= ~ USART_RXEN_bm;
        LOG("Initializing AVR");
        initializeAtTiny();
        // enable watchdog
        wdt_enable();

        //pinMode(DEBUG_PIN, OUTPUT);
        //digitalWrite(DEBUG_PIN, LOW);
        // disable power to other systems
        pinMode(DCDC_PWR, INPUT);
        // enable the AVR_IRQ as input so that we can observe if ESP wants something
        pinMode(AVR_IRQ, INPUT);
        // headphones are input pin as well
        pinMode(HEADPHONES, INPUT);
        // audio source is output, set it low by default
        pinMode(AUDIO_SRC, OUTPUT);
        digitalWrite(AUDIO_SRC, LOW);
        // set sleep to full power down and enable sleep feature
        set_sleep_mode(SLEEP_MODE_PWR_DOWN);
        sleep_enable();     
        // because this is poweron, delay a bit so that all voltages in the circuit can stabilize a bit, 200ms should do the trick
        delay(200); 
        
        initializeRTC();

        // Initialize ADC0
        initializeMeasurementsADC();

        initializeAudioCapture();

        // enable control interrupts for buttons
        controlBtn_.setInterrupt(controlButtonChanged);
        volumeBtn_.setInterrupt(volumeButtonChanged);
        // initialize comms
        initializeI2C();
        // proceed with wakeup
        wakeup();
    }

    static void loop() {
        if (status_.tick)
            tick();
        if (status_.i2cRxReady)
            processCommand();
        // if the measurement (headphones, voltage, temp, ...) is ready, measure
        if (ADC0.INTFLAGS & ADC_RESRDY_bm) {
            measurementsADCReady();
            if (undervoltageCountdown_ == 0) {
                criticalBatteryWarning();
                sleep();
            }
        }

    }

private:
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

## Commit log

2021-02-08 Some work on case, schematic and pcb layout
    [board.dxf, player.skp]
2021-02-09 Updated case & board size
    [board.dxf]
2021-02-09 board fixes
2021-02-11 some work on smaller pcb case
2021-02-15 case redesign, audio board
2021-02-17 Case should be finished, including box
    [board.dxf, board.skp, case.skp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]
2021-02-18 Case ready, some work on pcb
    [case.dxf, case.skp, plexiglass.dxf]
2021-02-22 larger board & case update, some routing
    [board.dxf, board.skp]
2021-02-24 low pass filter instead of i2s dac
2021-02-26 control board almost done
2021-02-27 case with updated speaker holder
    [case.dxf, case.skp, plexiglass.dxf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]
2021-02-27 regulators behind switch
2021-03-01 Case before ordering
    [case.dxf, case.skp]
2021-03-01 enable pin on converters used in schematics
2021-03-03 Rotary encoder working.
2021-03-04 Audio schematics added, updated pcb layout
2021-03-07 Some work on i2c slave.
    Getting used to the new TWI api on tiny.
2021-03-08 I2C and WakeUp working.
    Volume can be set as a proof.
2021-03-12 Stations switching works.
    Button presses, commands, avr code refactoring.
2021-03-15 Audio ADC lights up neopixels crudely.
2021-03-16 Bugfixes & esp irq basic timer.
    [attiny.ino, state.h]
2021-03-21 Sleep & voltage & temp.
    Voltage and temperature are not precise.
2021-03-21 Numerous fixes.
    Proper sampling for headphones, vcc and temperature. VCC detected
    without the need of a pin.
    [attiny.ino, esp8266.ino, state.h]
2021-03-22 AC coupled audio
2021-03-23 Radio switched to mono.
    Fewer components and improves reception quality which is more
    important in our setup.
2021-03-24 PCB redesign
2021-03-30 New pcb layout.
    Pin changes for both AVR and ESP.
2021-05-05 PCB design almost ready. Updates to case
    [board-large.dxf, board.dxf, board.skp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]
2021-05-07 dcdc power in input state when not active
2021-05-11 Inductor pattern updated
    [box.dxf, player.dxf, plexiglass-2mm.dxf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]
2021-06-20 Board layout v 1.1
    [board-large.dxf]
2021-07-01 Both targets updated to platform.io
    [board-large.dxf, board.dxf, board.skp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]
2021-07-04 Some simplifications to the AVR.
    [sync] Audio source not controlled by AVR anymore. Also state changed. Most likely won't compile.
    [attiny.cpp, inputs.h, state.h]
2021-07-06 AVR keep track of voltage and temperature.
2021-07-06 Both chips can be flashed.
    Some I2C code. Not working yet. delay() not working on attiny, use
    _delay_ms().
    [attiny.cpp, esp8266.cpp]
2021-07-07 I2C works.
2021-07-07 Temperature reports stuff too.
2021-07-08 I2C messages can be sent
2021-07-09 Bootstrap, jquery, mp3 encoder added to application.
    SD card initialized. Some work on the modes (radio & mp3).
2021-07-14 Tiny flashes LEDs.
    Wifi connecting & connected blinky.
2021-07-15 Cleaner messages & state.
    Volume LEDs.
2021-07-16 Low battery warning on attiny and leds.
2021-07-16 ESP won't start in SCL and SDA are held low during startup.
    [esp8266.cpp]
2021-07-22 hue changes in night light.
    Volume and control colors no longer in state, ESP will send lights commands itself.
    [attiny.cpp, color.h, esp8266.cpp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]
2021-07-23 Nightlights can be controlled.
    Neopixels mostly controlled from ESP (control & volume feedback). Minor improvements and fixes.
    [attiny.cpp, esp8266.cpp, state.h]
2021-07-24 Decals & board updates.
2021-07-24 Neopixel strip reworked.
    Lights changed, notifications working in night lights as well.
    [attiny.cpp, color.h, esp8266.cpp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]
2021-07-25 some updates to power pcb
2021-07-25 ATTiny critical baterry poweroff and warning lights.
2021-07-25 audiolights do some stuff.
    8kHz timer for recording drafted.
2021-07-27 [sync] basics for manual I2C
2021-07-27 [sync] some more i2c prototyping.
2021-07-27 I2C interrupt can send state.
2021-07-28 PT8211 I2S DAC.
    Script for platformio to patch arduino core so that I2S uses the Japanese format that PT8211 uses. Fixed mp3 tracks selection.
    [attiny.cpp, esp8266.cpp]
2021-07-28 Back to faster I2C development
2021-07-28 I2C slave finished, can send & receive like it did before.
2021-07-29 Voltage and temperature moved from the ISR
2021-07-29 Voltage & Temp measurements use no irqs.
2021-07-30 Recording buffer transmission over I2C works, stored in WAV file on SD card.
2021-07-31 State updates are behind interrupt disable. Audio src pin updated on mode change.
2021-07-31 Status sent after any non-status I2C slave tx.
2021-08-02 Better lights algorithm. Minor fixes.
    [attiny.cpp, esp8266.cpp, state.h]
2021-08-03 Fixed invalid recording frames.
    [attiny.cpp, esp8266.cpp]
2021-08-05 Long button press progress bar delayed.
2021-08-06 Double button long press.
    Turns the wifi on/off. Minor code cleanups. Telegram bot idea.
2021-08-08 Settings switched to JSON.
    Cheaper log, some more work on telegram bot. Exception decoder in monitor.
2021-08-09 printf directly on serial for logging. Bot settings read from JSON.
2021-08-15 Schematic updated (wrong values)
2021-08-17 More code to the player, I2C supports repeated starts.
2021-08-18 RTC & poweron simplified. More stuff ported.
2021-08-19 [sync] Error id double long press detection.
    [attiny.cpp, state.h]
2021-08-21 Schematic should be done. Some work on PCB
2021-08-22 More PCB layout & traces
2021-08-25 Through holes made larger for easier soldering
2021-09-08 Board rev v2 almost done
    [player.skp]
2021-09-15 Board rev v2.0 as submitted
2021-09-15 Beginning of the final version.
    Hopefully. Basic ESP and AVR, huge code refactorings, simplifications, more efficient I2C comms, messages.
2021-09-19 Basic mp3, radio and night lights support.
    Bugfixes in comms.
    [attiny.cpp, config.h, esp8266.cpp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]
2021-10-10 BOM added
2021-10-23 Audio lights, initial power on, volume & control bars shown even if turn does not change value.
2021-10-27 AVR buffers fixed, serial log enabled on extra pin. ESP I2C messages retries.
    [attiny.cpp, esp8266.cpp, state.h]
2021-10-28 Messages can be recorded. Power timeout.
2021-10-29 Power on reacts immediately when button pressed long enough.
2021-10-29 Timeout fixed. Basic binary clock mode added.
    [attiny.cpp, esp8266.cpp, state.h]
2021-10-29 LC filter for audio power line
2021-11-01 ATTiny does charging & battery detection, headphones, better binary clock and timed critical battery events.
2021-11-04 Updated board
2021-11-06 PCB v2.1
2021-11-07 Updated BOM v 2.1
2021-11-08 Notifications removed, slow fade of lights before poweroff.
2021-11-08 Notifications make their leds black when not used.
2021-11-09 Proper poweroff synchronization between AVR and ESP.
2021-11-09 Fixed charging detection bug.
    [attiny.cpp, esp8266.cpp]
2021-11-11 Telegram bot updates do stuff. So do commands. Reset message.
    [attiny.cpp, esp8266.cpp]
2021-11-14 Temperature fixed.
2021-11-16 Birthday mode added.
    Various UX fixes.
    [attiny.cpp, esp8266.cpp, state.h]
2021-11-16 OTA for arduino removed to lower the RAM footprint.
2021-11-17 Numerous fixes and improvements in robustness.
    AVR WDT, proper ESP reset, better settings, timezone support, max volume settings.
    [attiny.cpp, config.h, esp8266.cpp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]
2021-11-21 Large refactoring of ESP code.
    Functionality in core player and swappable modes. Almost done, sync & greeting modes remain to be updated. No testing of the rest.
    [attiny.cpp, config.h, esp8266.cpp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]
2021-11-23 Noise filter on recorder drafted.
    [esp8266.cpp]
2021-11-23 Noise filter for recorder.
    Numerous bugfixes after the refactoring.
    [attiny.cpp, config.h, esp8266.cpp]
2021-11-24 SD card format triggered from server.
    Minor fixes.
    [attiny.cpp, esp8266.cpp, state.h]
2021-12-10 More fixes to the app.
    [esp8266.cpp]
2021-12-11 Almost completely working webserver.
    Fixes to alarm and minor improvements.
    [config.h, esp8266.cpp]
2021-12-16 Number of fixes and stability improvements.
    [esp8266.cpp]
2021-12-19 Time synced at each WiFi connection. Minor fixes.
    [esp8266.cpp]
2021-12-21 mp3 track and radio station frequency changes update control value as well.
